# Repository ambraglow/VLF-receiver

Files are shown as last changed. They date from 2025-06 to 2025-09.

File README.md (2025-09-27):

# E202 VLF receiver
This is my own spin on the E202 VLF receiver design, as a PCB.
It features 2.1mm mounting holes, a line-out audio transformer (so it can be directly connected to a soundcard) and a volume control slider.  

top

## June update
Today on June 16th i received a batch of boards, thanks to [PCBWay](https://www.pcbway.com/) for sponsoring this project!
The ordering process is pretty straightforward, i used their Kicad plugin for exporting production files and uploading them to their system.
Compared to their conpetitors, different soldermask colors don't add too much cost to production and look stunning, shipping times aren't too bad either, it took less than a week for the PCBs to arrive to Italy, it was an overall pleasant experience and their support is also really helpful as i had to ask for help with my order at some point, because of a different revision of my board.
Here's some pictures of the boards, they really look stunning in yellow soldermask.

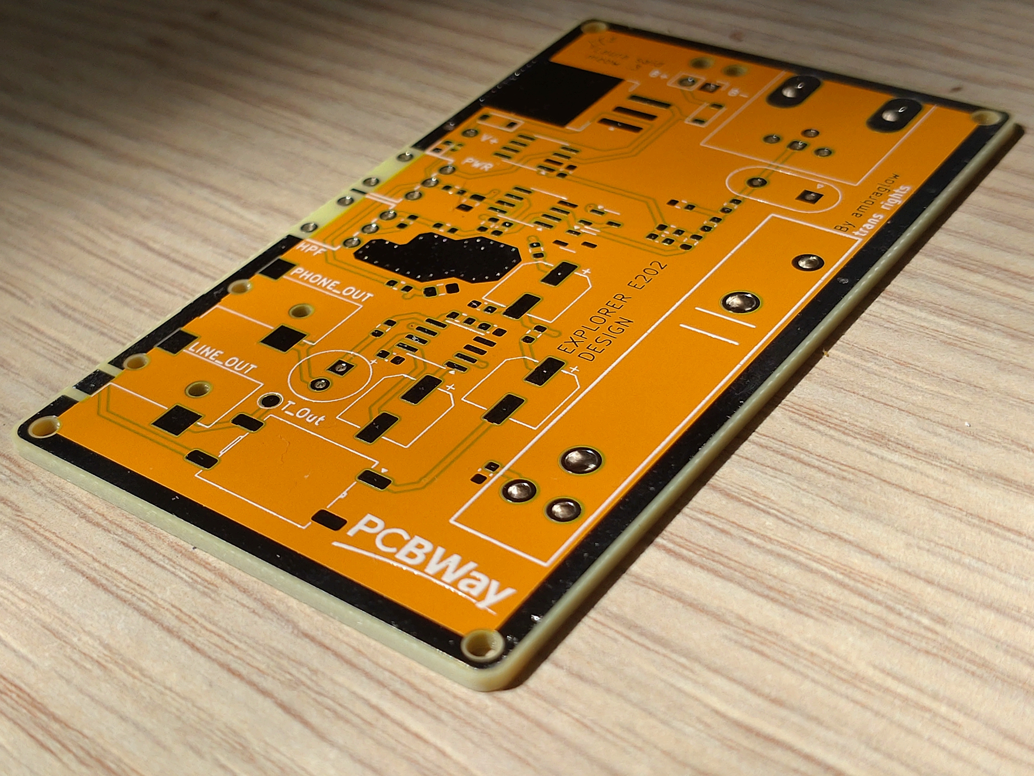
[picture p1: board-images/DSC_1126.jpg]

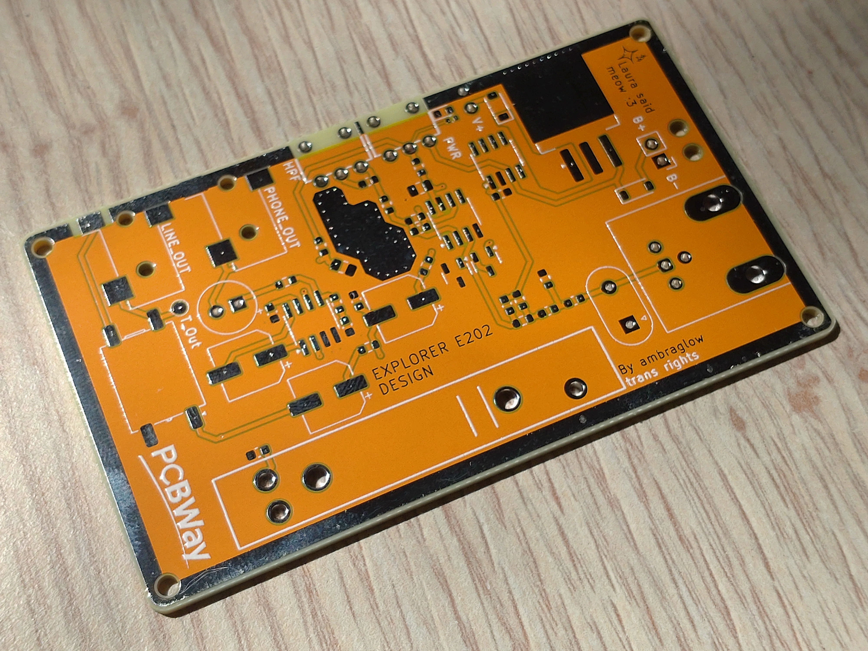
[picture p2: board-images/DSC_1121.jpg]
  

Functionally they should work, but that will be a problem for future me :D  

## Credits & Resources
[Original schematic design](http://www.vlf.it/romero2/explorer-e202.html) by Renato | [rendered PCB images, thanks to Lina's plugin](https://github.com/linalinn/kicad-render)

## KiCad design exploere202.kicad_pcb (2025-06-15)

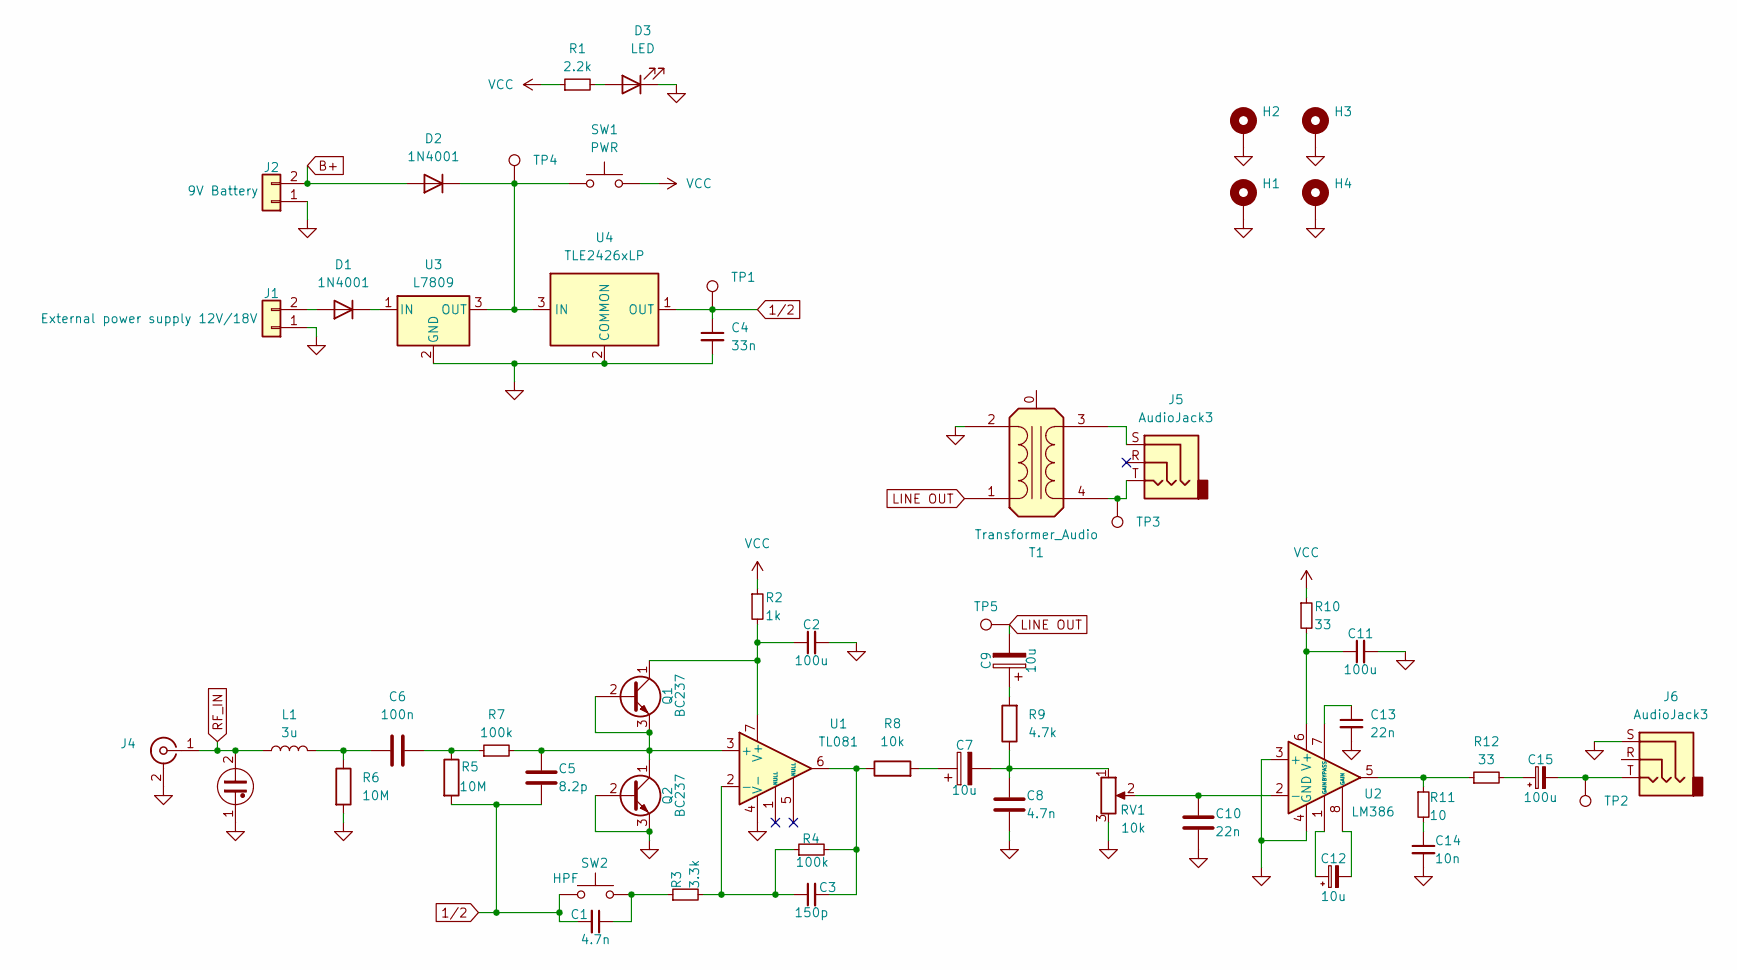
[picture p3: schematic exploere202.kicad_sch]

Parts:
C1, C8: 4.7n; C_0603_1608Metric
C2, C11: 100u; C_0805_2012Metric
C3: 150p; C_0603_1608Metric
C4: 33n; C_0603_1608Metric
C5: 8.2p; C_0603_1608Metric
C6: 100n; C_0603_1608Metric
C7, C9, C12: 10u; CP_Elec_6.3x4.5
C10, C13: 22n; C_0603_1608Metric
C14: 10n; C_0603_1608Metric
C15: 100u; CP_Radial_D6.3mm_P2.50mm
D1, D2: 1N4001; D_SOD-123
D3: LED; LED_0603_1608Metric
H1, H2, H3, H4: MountingHole_Pad; MountingHole_2.1mm
J1: External power supply 12V/18V; PinHeader_1x02_P2.54mm_Vertical
J2: 9V Battery; PinHeader_1x02_P2.54mm_Vertical
J4: Conn_Coaxial; BNC_Win_364A2x95_Horizontal
J5, J6: AudioJack3; Jack_3.5mm_CUI_SJ-3523-SMT_Horizontal
L1: 3u; L_0603_1608Metric
NE1: Lamp_Neon; Valve_Glimm
Q1, Q2: BC237; SOT-23-3
R1: 2.2k; R_0402_1005Metric
R2: 1k; R_0603_1608Metric
R3: 3.3k; R_0603_1608Metric
R4, R7: 100k; R_0603_1608Metric
R5, R6: 10M; R_0603_1608Metric
R8: 10k; R_0603_1608Metric
R9: 4.7k; R_0603_1608Metric
R10, R12: 33; R_0603_1608Metric
R11: 10; R_0603_1608Metric
RV1: 10k; RES-ADJ-TH_RS30111A602N
SW1: PWR; SW-TH_ST-0-102-C03-N003-RS
SW2: HPF; SW-TH_ST-0-102-C03-N003-RS
T1: Transformer_Audio; Transformer_ED8_4-Lead_10.5x8mm_P5mm
TP1, TP2, TP4, TP5: TestPoint; TestPoint_Pad_D2.5mm
TP3: TestPoint; TestPoint_Pad_D1.5mm
U1: TL081; SOIC-8-1EP_3.9x4.9mm_P1.27mm_EP2.29x3mm
U2: LM386; SOIC-8-1EP_3.9x4.9mm_P1.27mm_EP2.29x3mm
U3: L7809; TO-263-3_TabPin2
U4: TLE2426xLP; SOIC-8-1EP_3.9x4.9mm_P1.27mm_EP2.29x3mm

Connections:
1/2: C1.2, C4.1, C5.2, R5.2, SW2.2, TP1.1, U4.1 (OUT)
B+: D2.2 (A), J2.2
GND: C2.2, C4.2, C8.2, C10.2, C11.2, C13.2, C14.2, D3.1 (K), H1.1, H2.1, H3.1, H4.1, J1.1, J2.1, J4.2 (Ext), J6.S, NE1.1, Q2.2 (B), Q2.3 (E), R6.2, RV1.3, T1.2 (AB), U1.4 (V-), U2.3 (+), U2.4 (GND), U3.2 (GND), U4.2 (COMMON)
LINE OUT: C9.2, T1.1 (AA), TP5.1
unnamed: C1.1, R3.1, SW2.1
unnamed: C3.2, R4.2, R8.1, U1.6
unnamed: C6.1, L1.2, R6.1
unnamed: C6.2, R5.1, R7.1
unnamed: C7.1, R8.2
unnamed: C7.2, C8.1, R9.1, RV1.1
unnamed: C9.1, R9.2
unnamed: C12.1, U2.1 (GAIN)
unnamed: C12.2, U2.8 (GAIN)
unnamed: C14.1, R11.2
unnamed: C15.1, R12.2
unnamed: C15.2, J6.T, TP2.1
unnamed: D1.2 (A), J1.2
unnamed: D1.1 (K), U3.1 (IN)
unnamed: D2.1 (K), SW1.1, TP4.1, U3.3 (OUT), U4.3 (IN)
unnamed: D3.2 (A), R1.2
unnamed: C5.1, Q1.2 (B), Q1.3 (E), Q2.1 (C), R7.2, U1.3 (+)
unnamed: C2.1, Q1.1 (C), R2.2, U1.7 (V+)
unnamed: R11.1, R12.1, U2.5
unnamed: J5.S, T1.3 (SA)
unnamed: J5.T, T1.4 (SB), TP3.1
unnamed: C3.1, R3.2, R4.1, U1.2 (-)
unnamed: C10.1, RV1.2, U2.2 (-)
unnamed: C13.1, U2.7 (BYPASS)
unnamed: C11.1, R10.2, U2.6 (V+)
RF_IN: J4.1 (In), L1.1, NE1.2
VCC: R1.1, R2.1, R10.1, SW1.2

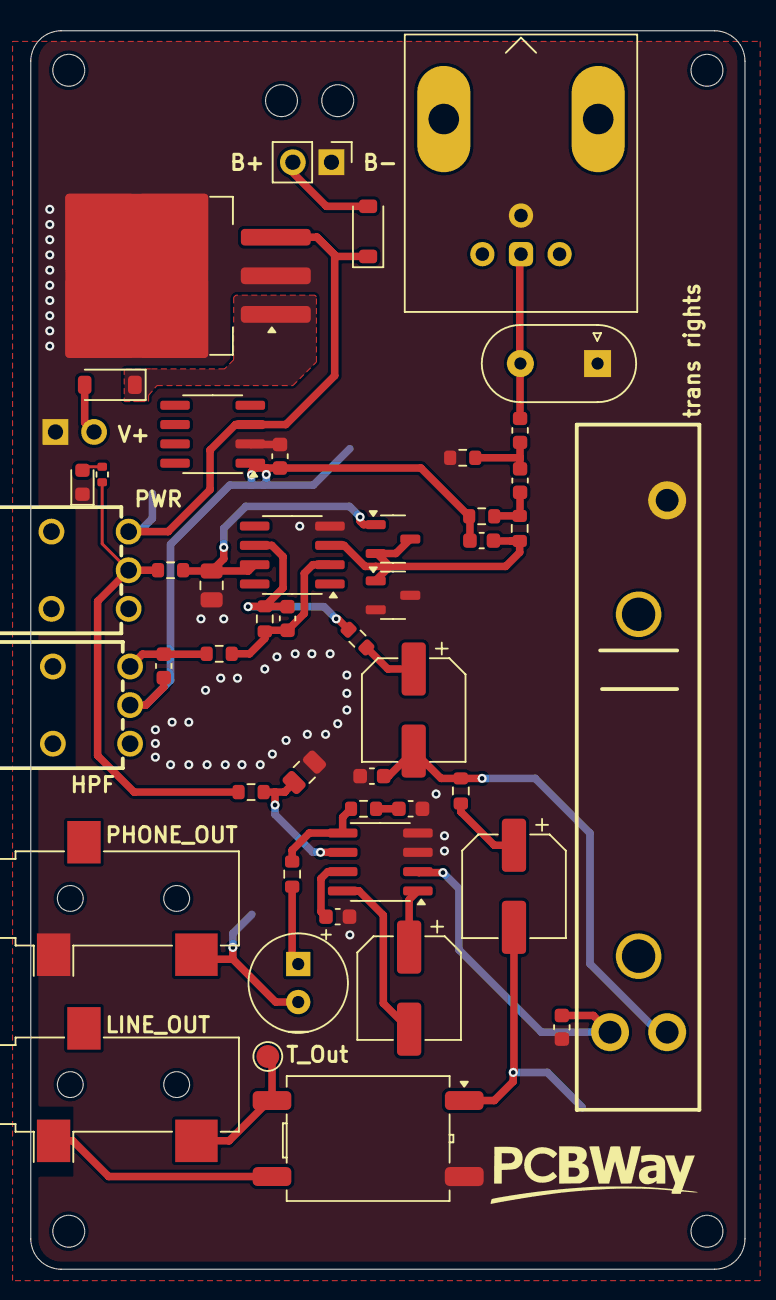
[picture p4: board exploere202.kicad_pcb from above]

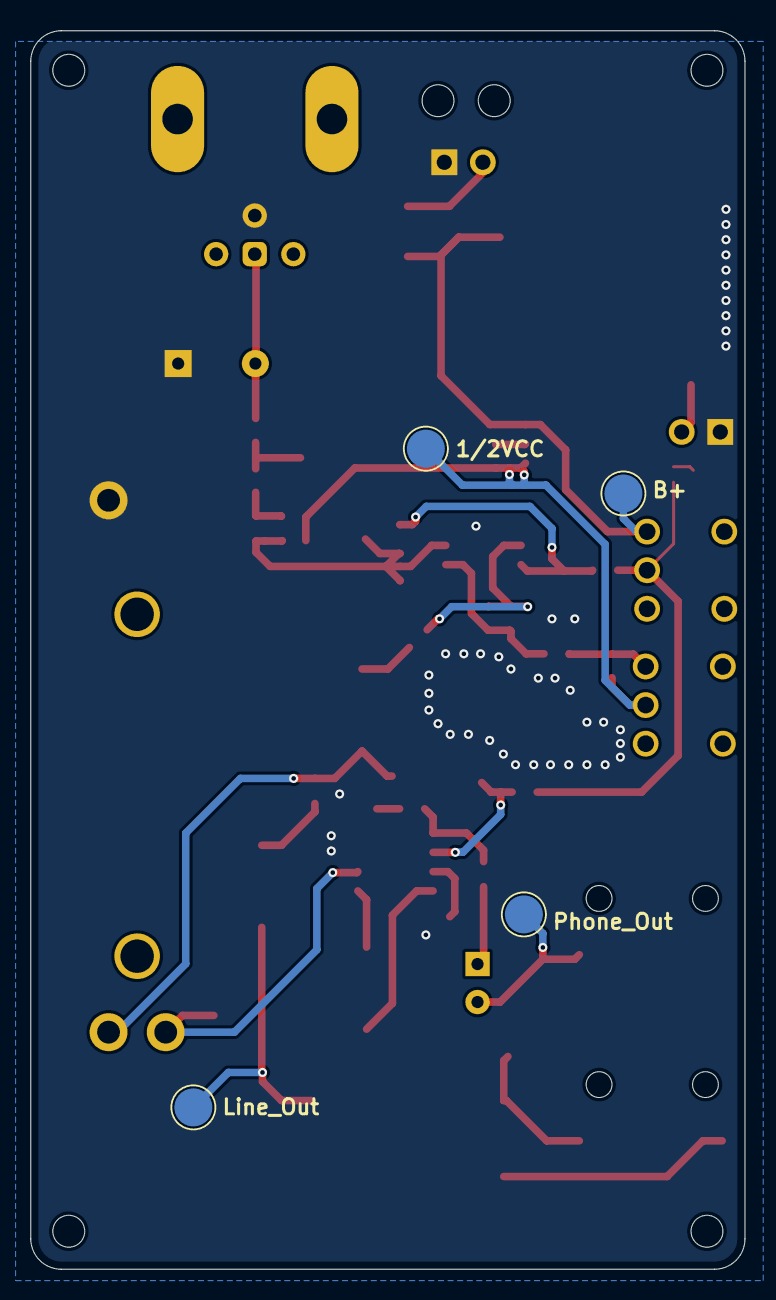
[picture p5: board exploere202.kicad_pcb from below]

Board: 2 copper layers, 47.0 x 81.5 mm, 56 parts (4 on the bottom side), 31 nets.

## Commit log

2025-06-16 add board images!
2025-06-16 board images in folder
